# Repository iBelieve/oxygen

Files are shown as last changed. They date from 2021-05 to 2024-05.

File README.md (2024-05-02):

# Oxygen F7 Flight Controller

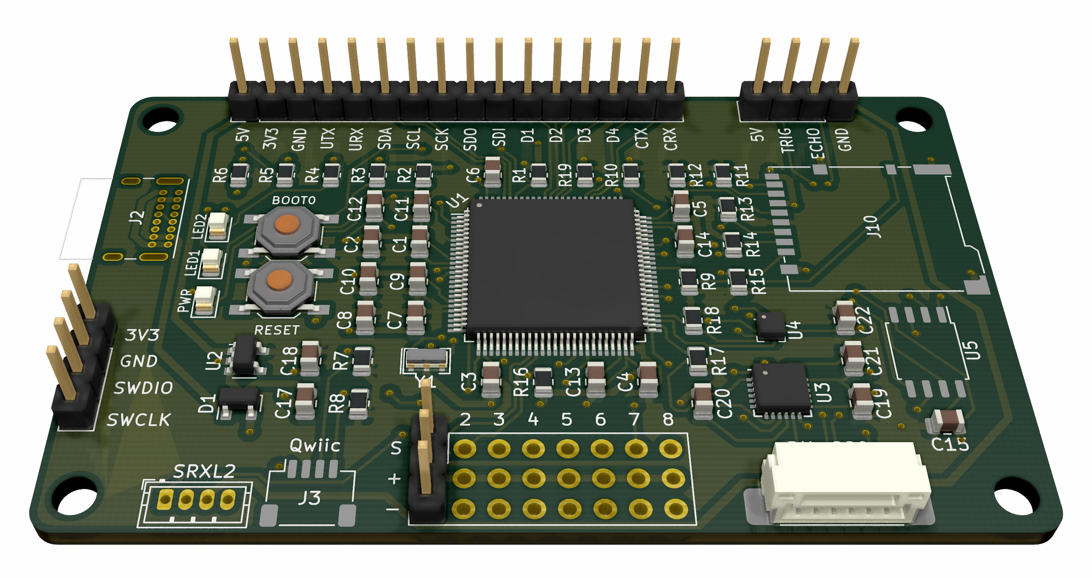
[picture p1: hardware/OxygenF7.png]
3D render of PCB


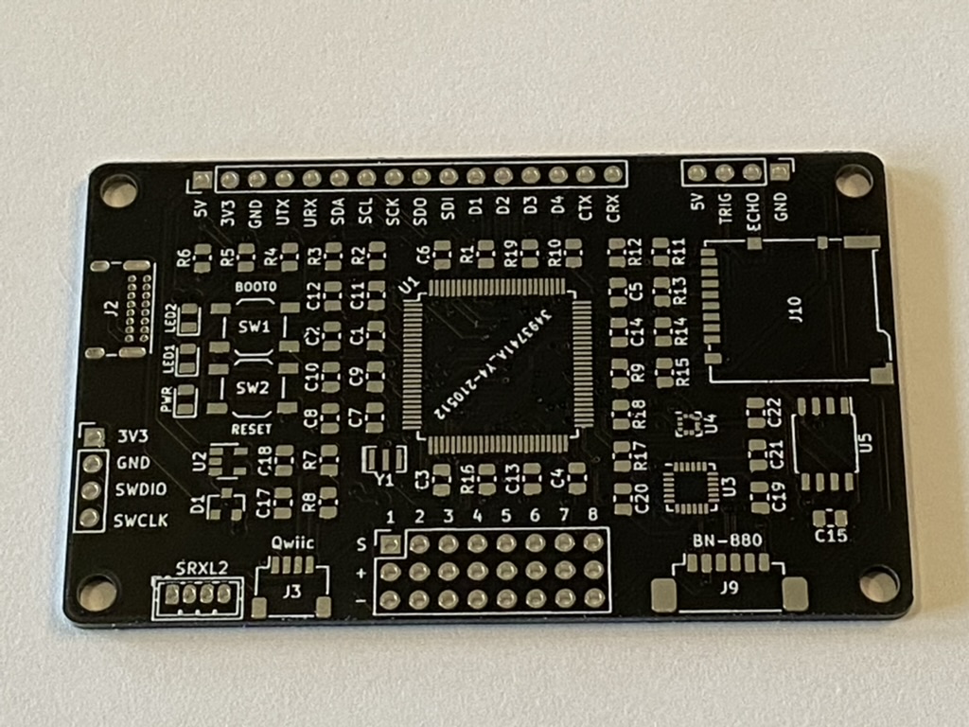
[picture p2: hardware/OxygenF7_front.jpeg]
Front of PCB

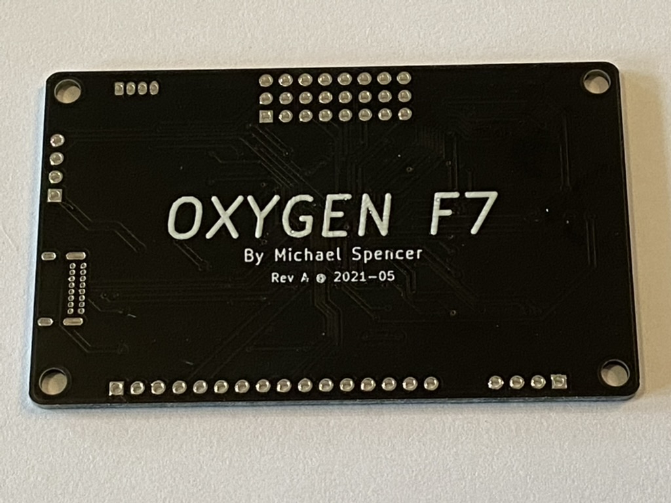
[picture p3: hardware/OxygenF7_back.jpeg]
Back of PCB

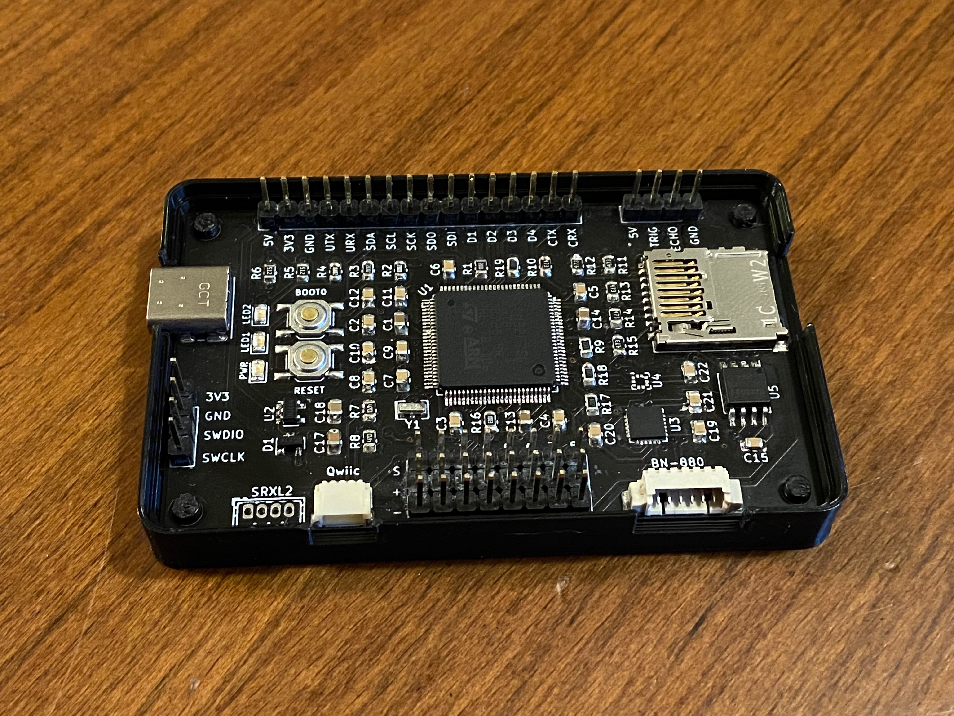
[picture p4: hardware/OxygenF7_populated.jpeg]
Populated PCB


## Hardware

- Designed for fixed-wing aircraft
- STM32F756
- MPU-6000 gyroscope & accelerometer
- BMP-388 barometer
- 8 PWM servo outputs
- SRXL2 receiver input
- Qwiic I2C port
- Connector for HC SR-04 ultrasonic distance sensor
- Connector for BN-880Q GPS and compass
- Header with various pins for debugging and experimentation
- USB-C
- microSD slot
- 128MB external flash memory

## Firmware

- Built with Rust
- Very early work-in-progress!!

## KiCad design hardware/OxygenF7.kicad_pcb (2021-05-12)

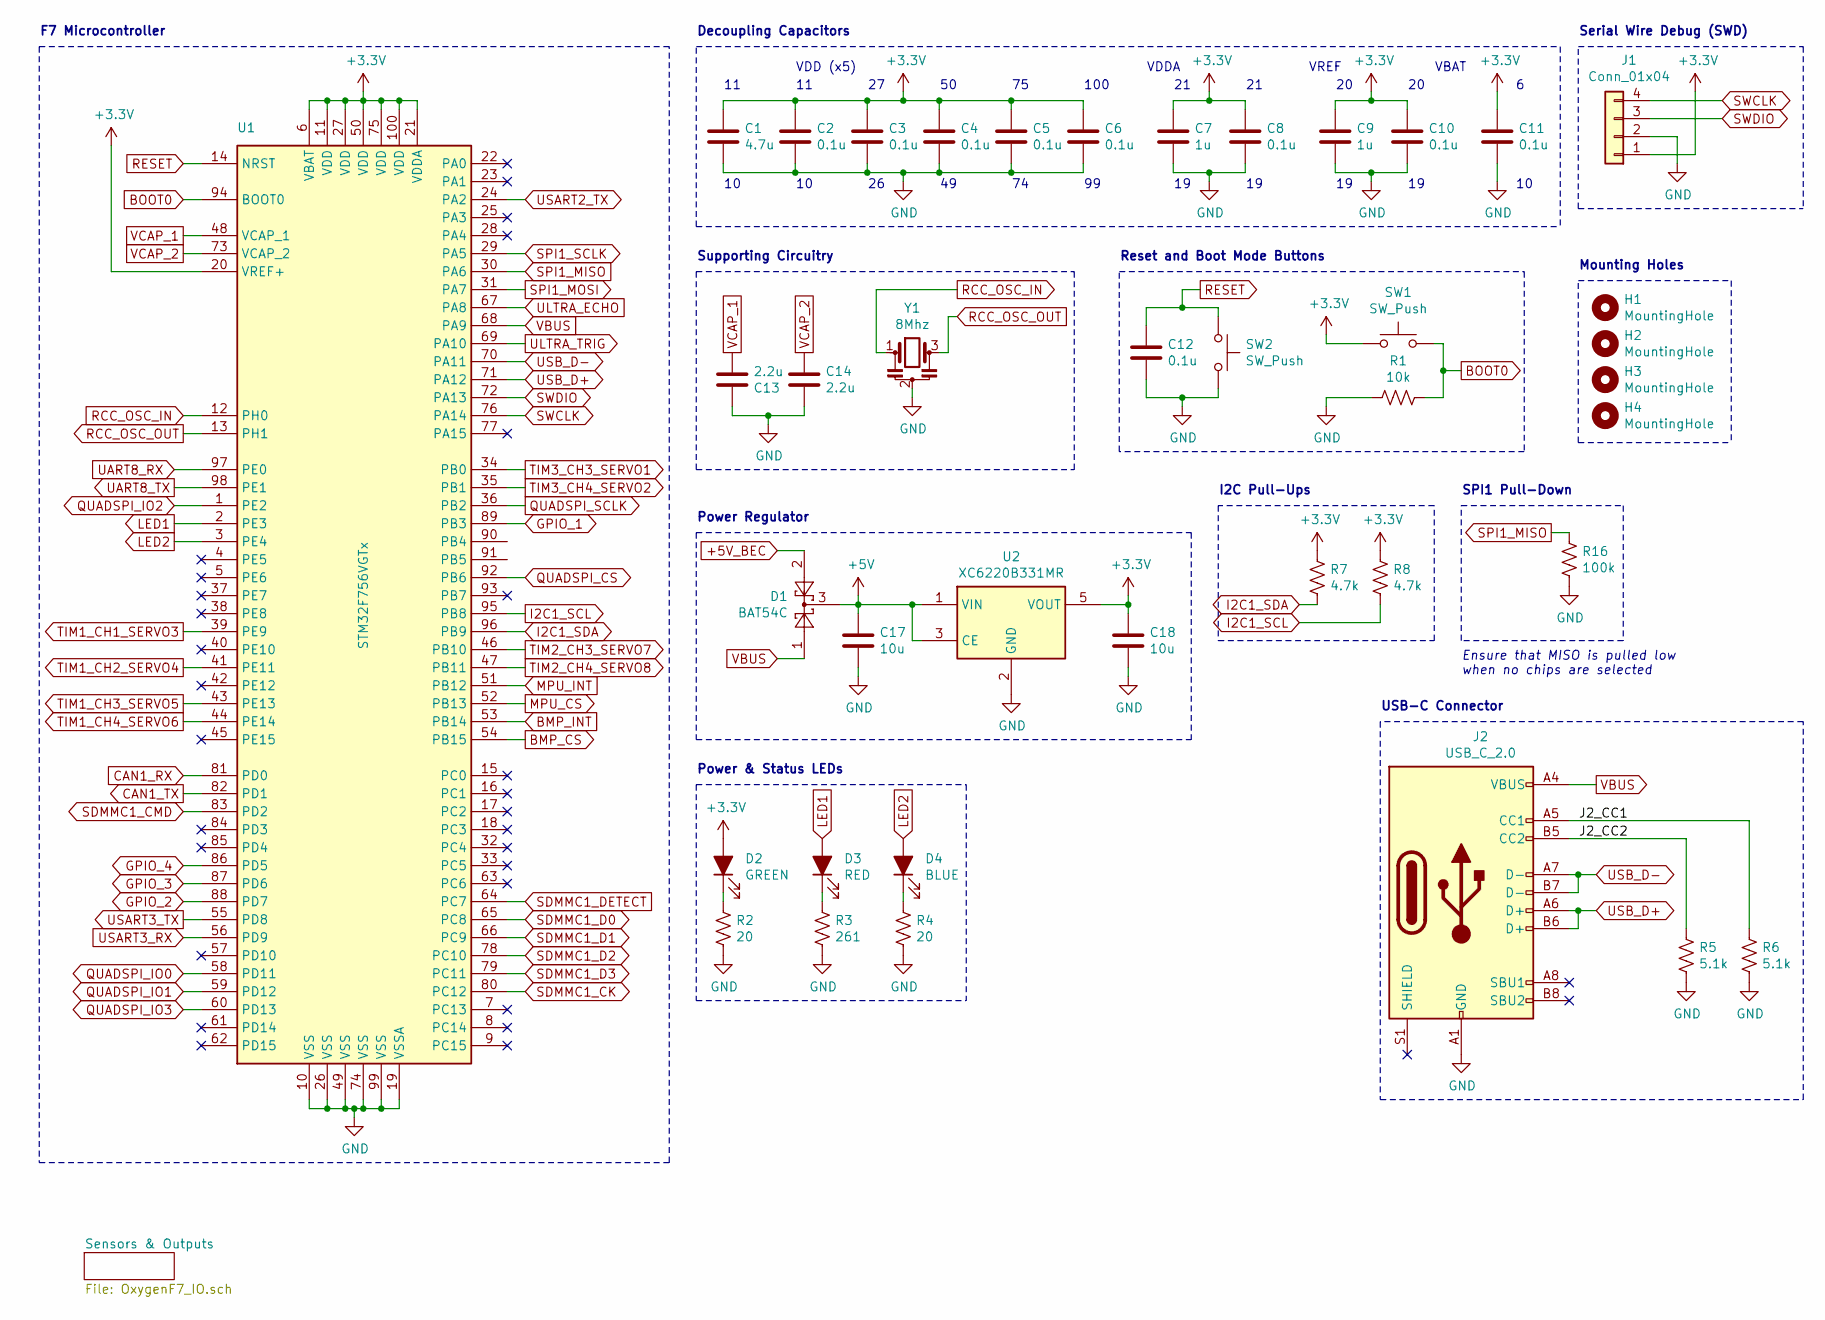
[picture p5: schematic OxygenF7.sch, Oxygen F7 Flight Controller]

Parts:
C1: 4.7u; C_0805_2012Metric; Part# CL21B475KPFNNNE
C2, C3, C4, C5, C6, C8, C10, C11, C12: 0.1u; C_0805_2012Metric; Part# CL21B104KBCNNNC‎
C7, C9: 1u; C_0805_2012Metric; Part# CL21B105KOFNNNG
C13, C14: 2.2u; C_0805_2012Metric; Part# CL21B225KPFNNNE
C17, C18: 10u; C_0805_2012Metric; Part# CL21B106KQQNNNG
D1: BAT54C; SOT-23; Part# BAT54CQ-7-F
D2: GREEN; LED_0805_2012Metric; Part# 150080GS75000
D3: RED; LED_0805_2012Metric; Part# 150080RS75000
D4: BLUE; LED_0805_2012Metric; Part# 150080BS75000
H1, H2, H3, H4: MountingHole; MountingHole_3.2mm_M3
J1: Conn_01x04; PinHeader_1x04_P2.54mm_Vertical; Part# PR20204VBNN
J2: USB_C_2.0; USB_C_Receptacle_GCT_USB4085; Part# USB4085-GF-A
R1: 10k; R_0805_2012Metric; Part# RMCF0805FT10K0
R2, R4: 20; R_0805_2012Metric; Part# RMCF0805FT20R0
R3: 261; R_0805_2012Metric; Part# RMCF0805FT261R
R5, R6: 5.1k; R_0805_2012Metric; Part# RMCF0805JT5K10
R7, R8: 4.7k; R_0805_2012Metric; Part# RMCF0805FT4K70
R16: 100k; R_0805_2012Metric; Part# RMCF0805FT100K
SW1, SW2: SW_Push; SW_SPST_TL3342; Part# TL3342F160QG/TR
U1: STM32F756VGTx; LQFP-100_14x14mm_P0.5mm; Part# STM32F756VGT6
U2: XC6220B331MR; SOT-23-5; Part# XC6220B331MR-G
Y1: 8Mhz; Resonator_SMD_muRata_CSTxExxV-3Pin_3.0x1.1mm; Part# CSTNE8M00GH5L000R0

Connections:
+3V3: C1.1, C2.1, C3.1, C4.1, C5.1, C6.1, C7.1, C8.1, C9.1, C10.1, C11.1, C18.1, D2.2 (A), J1.1, R7.1, R8.1, SW1.1, U1.6 (VBAT), U1.11 (VDD), U1.20 (VREF+), U1.21 (VDDA), U1.27 (VDD), U1.50 (VDD), U1.75 (VDD), U1.100 (VDD), U2.5 (VOUT); also elsewhere on the board
+5V: C17.1, D1.3, U2.1 (VIN), U2.3 (CE); also elsewhere on the board
+5V_BEC: D1.2; also elsewhere on the board
/J2_CC1: J2.A5 (CC1), R6.1
/J2_CC2: J2.B5 (CC2), R5.1
BMP_CS: U1.54 (PB15); also elsewhere on the board
BMP_INT: U1.53 (PB14); also elsewhere on the board
BOOT0: R1.2, SW1.2, U1.94 (BOOT0)
CAN1_RX: U1.81 (PD0); also elsewhere on the board
CAN1_TX: U1.82 (PD1); also elsewhere on the board
GND: C1.2, C2.2, C3.2, C4.2, C5.2, C6.2, C7.2, C8.2, C9.2, C10.2, C11.2, C12.2, C13.1, C14.2, C17.2, C18.2, J1.2, J2.A1 (GND), J2.A12 (GND), J2.B1 (GND), J2.B12 (GND), R1.1, R2.2, R3.2, R4.2, R5.2, R6.2, R16.2, SW2.2, U1.10 (VSS), U1.19 (VSSA), U1.26 (VSS), U1.49 (VSS), U1.74 (VSS), U1.99 (VSS), U2.2 (GND), Y1.2; also elsewhere on the board
GPIO_1: U1.89 (PB3); also elsewhere on the board
GPIO_2: U1.88 (PD7); also elsewhere on the board
GPIO_3: U1.87 (PD6); also elsewhere on the board
GPIO_4: U1.86 (PD5); also elsewhere on the board
I2C1_SCL: R8.2, U1.95 (PB8); also elsewhere on the board
I2C1_SDA: R7.2, U1.96 (PB9); also elsewhere on the board
LED1: D3.2 (A), U1.2 (PE3)
LED2: D4.2 (A), U1.3 (PE4)
MPU_CS: U1.52 (PB13); also elsewhere on the board
MPU_INT: U1.51 (PB12); also elsewhere on the board
unnamed: D2.1 (K), R2.1
unnamed: D3.1 (K), R3.1
unnamed: D4.1 (K), R4.1
QUADSPI_CS: U1.92 (PB6); also elsewhere on the board
QUADSPI_IO0: U1.58 (PD11); also elsewhere on the board
QUADSPI_IO1: U1.59 (PD12); also elsewhere on the board
QUADSPI_IO2: U1.1 (PE2); also elsewhere on the board
QUADSPI_IO3: U1.60 (PD13); also elsewhere on the board
QUADSPI_SCLK: U1.36 (PB2); also elsewhere on the board
RCC_OSC_IN: U1.12 (PH0), Y1.1
RCC_OSC_OUT: U1.13 (PH1), Y1.3
RESET: C12.1, SW2.1, U1.14 (NRST)
SDMMC1_CK: U1.80 (PC12); also elsewhere on the board
SDMMC1_CMD: U1.83 (PD2); also elsewhere on the board
SDMMC1_D0: U1.65 (PC8); also elsewhere on the board
SDMMC1_D1: U1.66 (PC9); also elsewhere on the board
SDMMC1_D2: U1.78 (PC10); also elsewhere on the board
SDMMC1_D3: U1.79 (PC11); also elsewhere on the board
SDMMC1_DETECT: U1.64 (PC7); also elsewhere on the board
SPI1_MISO: R16.1, U1.30 (PA6); also elsewhere on the board
SPI1_MOSI: U1.31 (PA7); also elsewhere on the board
SPI1_SCLK: U1.29 (PA5); also elsewhere on the board
SWCLK: J1.4, U1.76 (PA14)
SWDIO: J1.3, U1.72 (PA13)
TIM1_CH1_SERVO3: U1.39 (PE9); also elsewhere on the board
TIM1_CH2_SERVO4: U1.41 (PE11); also elsewhere on the board
TIM1_CH3_SERVO5: U1.43 (PE13); also elsewhere on the board
TIM1_CH4_SERVO6: U1.44 (PE14); also elsewhere on the board
TIM2_CH3_SERVO7: U1.46 (PB10); also elsewhere on the board
TIM2_CH4_SERVO8: U1.47 (PB11); also elsewhere on the board
TIM3_CH3_SERVO1: U1.34 (PB0); also elsewhere on the board
TIM3_CH4_SERVO2: U1.35 (PB1); also elsewhere on the board
UART8_RX: U1.97 (PE0); also elsewhere on the board
UART8_TX: U1.98 (PE1); also elsewhere on the board
ULTRA_ECHO: U1.67 (PA8); also elsewhere on the board
ULTRA_TRIG: U1.69 (PA10); also elsewhere on the board
USART2_TX: U1.24 (PA2); also elsewhere on the board
USART3_RX: U1.56 (PD9); also elsewhere on the board
USART3_TX: U1.55 (PD8); also elsewhere on the board
USB_D+: J2.A6 (D+), J2.B6 (D+), U1.71 (PA12)
USB_D-: J2.A7 (D-), J2.B7 (D-), U1.70 (PA11)
VBUS: D1.1, J2.A4 (VBUS), J2.A9 (VBUS), J2.B4 (VBUS), J2.B9 (VBUS), U1.68 (PA9)
VCAP_1: C13.2, U1.48 (VCAP_1)
VCAP_2: C14.1, U1.73 (VCAP_2)

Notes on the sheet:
Decoupling Capacitors
VDD (x5)
VDDA
F7 Microcontroller
VBAT
100
USB-C Connector
Power & Status LEDs
Supporting Circuitry
Power Regulator
Serial Wire Debug (SWD)
VREF
Mounting Holes
Reset and Boot Mode Buttons
I2C Pull-Ups
SPI1 Pull-Down
Ensure that MISO is pulled low when no chips are selected

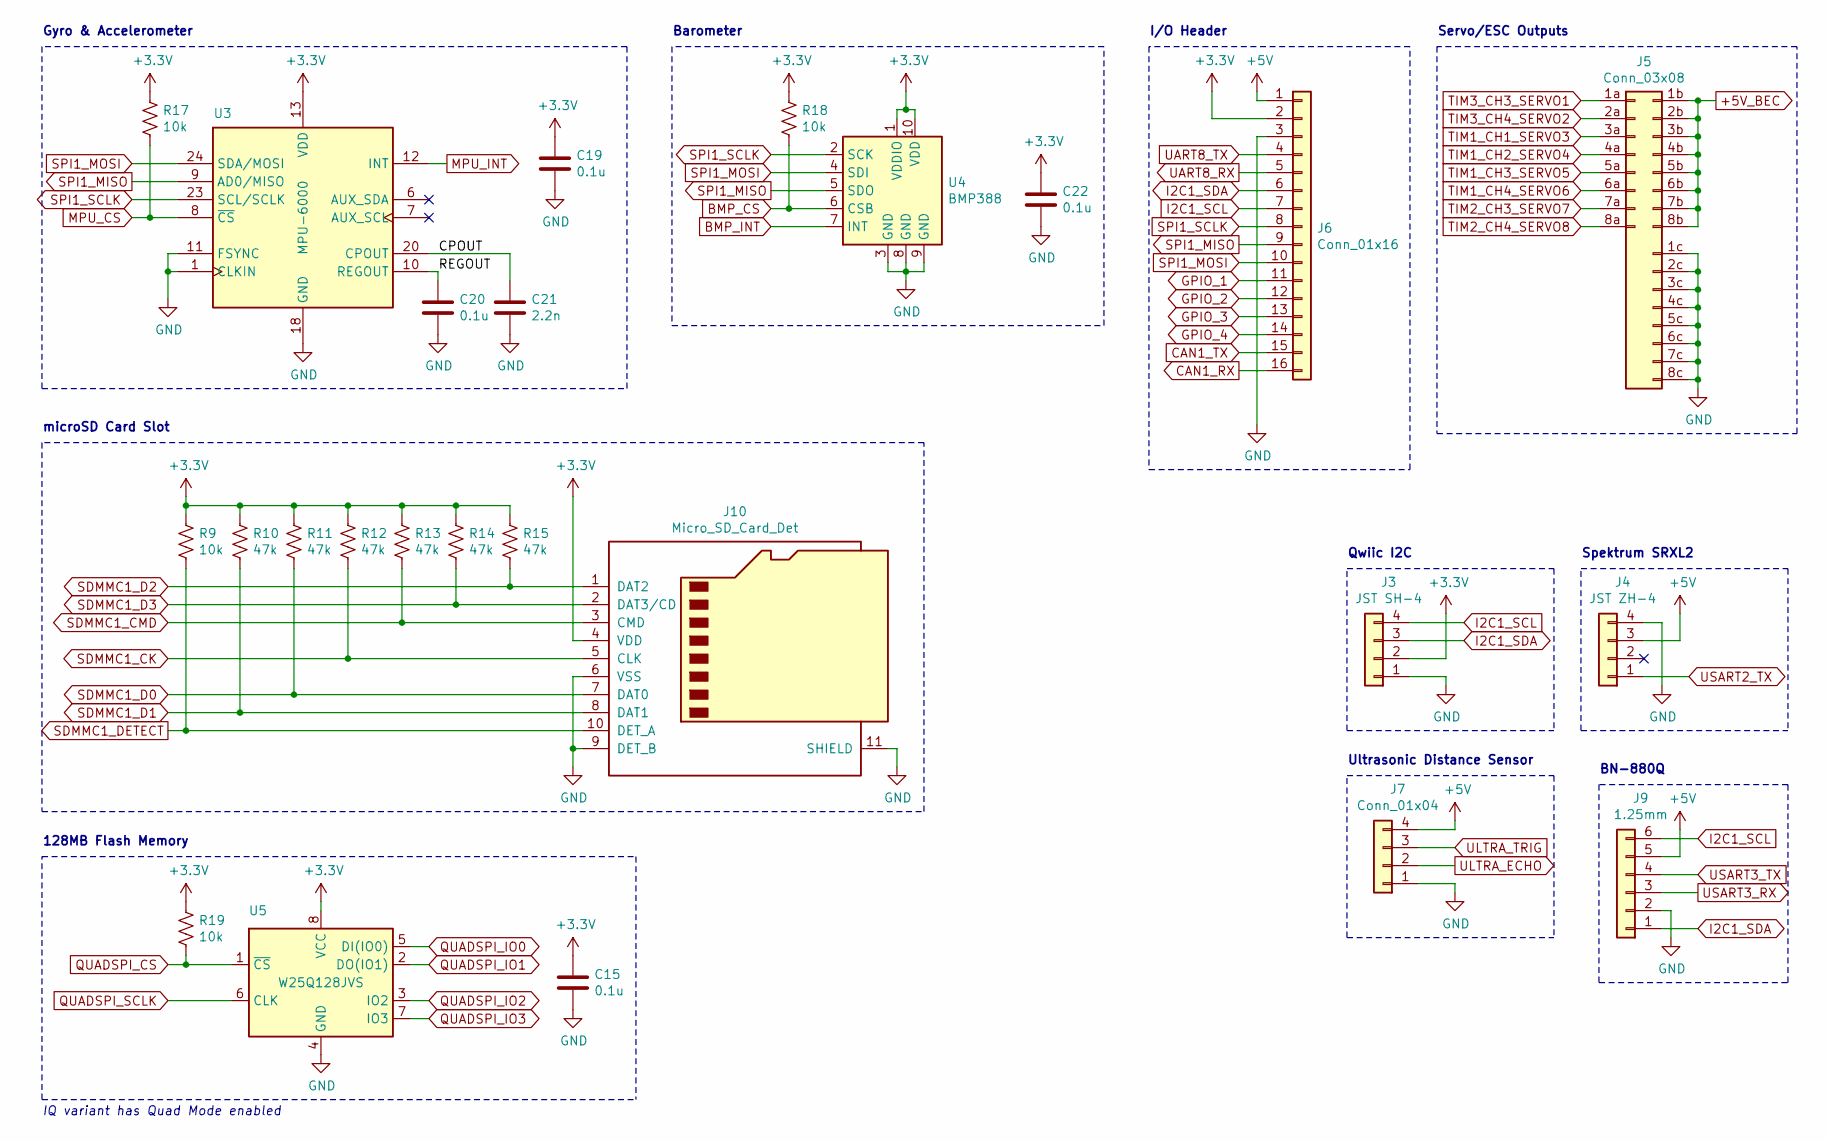
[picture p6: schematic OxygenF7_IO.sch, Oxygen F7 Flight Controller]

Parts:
C15, C19, C20, C22: 0.1u; C_0805_2012Metric; Part# CL21B104KBCNNNC‎
C21: 2.2n; C_0805_2012Metric; Part# CL21B222KBANNNC
J3: JST SH-4; JST_SH_SM04B-SRSS-TB_1x04-1MP_P1.00mm_Horizontal; Part# SM04B-SRSS-TB(LF)(SN)
J4: JST ZH-4; JST_ZH_B4B-ZR_1x04_P1.50mm_Vertical; Part# B4B-ZR-SM4-TF(LF)(SN)
J5: Conn_03x08; PinHeader_08x03_P2.54mm_Vertical; Part# PR20208VBNN:3
J6: Conn_01x16; PinHeader_1x16_P2.54mm_Vertical; Part# 61301611121
J7: Conn_01x04; PinHeader_1x04_P2.54mm_Vertical; Part# PR20204VBNN
J9: 1.25mm; 10114830-10106LF_P1.25mm_Horizontal; Part# 10114830-10106LF
J10: Micro_SD_Card_Det; microSD_HC_Hirose_DM3BT-DSF-PEJS; Part# DM3BT-DSF-PEJS
R9, R17, R18, R19: 10k; R_0805_2012Metric; Part# RMCF0805FT10K0
R10, R11, R12, R13, R14, R15: 47k; R_0805_2012Metric; Part# RMCF0805JT47K0
U3: MPU-6000; InvenSense_QFN-24_4x4mm_P0.5mm; Part# MPU-6000
U4: BMP388; LGA-10_2x2mm_P0.5mm; Part# BMP388
U5: W25Q128JVS; SOIC-8_5.23x5.23mm_P1.27mm; Part# W25Q128JVSIQ

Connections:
+3V3: C15.1, C19.1, C22.1, J3.2, J6.2, J10.4 (VDD), R9.1, R10.1, R11.1, R12.1, R13.1, R14.1, R15.1, R17.1, R18.1, R19.1, U3.13 (VDD), U4.1 (VDDIO), U4.10 (VDD), U5.8 (VCC); also elsewhere on the board
+5V: J4.3, J6.1, J7.4, J9.5; also elsewhere on the board
+5V_BEC: J5.1b, J5.2b, J5.3b, J5.4b, J5.5b, J5.6b, J5.7b, J5.8b; also elsewhere on the board
/Sensors & Outputs/CPOUT: C21.1, U3.20 (CPOUT)
/Sensors & Outputs/REGOUT: C20.1, U3.10 (REGOUT)
BMP_CS: R18.2, U4.6 (CSB); also elsewhere on the board
BMP_INT: U4.7 (INT); also elsewhere on the board
CAN1_RX: J6.16; also elsewhere on the board
CAN1_TX: J6.15; also elsewhere on the board
GND: C15.2, C19.2, C20.2, C21.2, C22.2, J3.1, J4.4, J5.1c, J5.2c, J5.3c, J5.4c, J5.5c, J5.6c, J5.7c, J5.8c, J6.3, J7.1, J9.2, J10.6 (VSS), J10.9 (DET_B), J10.11 (SHIELD), U3.1 (CLKIN), U3.11 (FSYNC), U3.18 (GND), U4.3 (GND), U4.8 (GND), U4.9 (GND), U5.4 (GND); also elsewhere on the board
GPIO_1: J6.11; also elsewhere on the board
GPIO_2: J6.12; also elsewhere on the board
GPIO_3: J6.13; also elsewhere on the board
GPIO_4: J6.14; also elsewhere on the board
I2C1_SCL: J3.4, J6.7, J9.6; also elsewhere on the board
I2C1_SDA: J3.3, J6.6, J9.1; also elsewhere on the board
MPU_CS: R17.2, U3.8 (~CS); also elsewhere on the board
MPU_INT: U3.12 (INT); also elsewhere on the board
QUADSPI_CS: R19.2, U5.1 (~CS); also elsewhere on the board
QUADSPI_IO0: U5.5 (DI(IO0)); also elsewhere on the board
QUADSPI_IO1: U5.2 (DO(IO1)); also elsewhere on the board
QUADSPI_IO2: U5.3 (IO2); also elsewhere on the board
QUADSPI_IO3: U5.7 (IO3); also elsewhere on the board
QUADSPI_SCLK: U5.6 (CLK); also elsewhere on the board
SDMMC1_CK: J10.5 (CLK), R12.2; also elsewhere on the board
SDMMC1_CMD: J10.3 (CMD), R13.2; also elsewhere on the board
SDMMC1_D0: J10.7 (DAT0), R11.2; also elsewhere on the board
SDMMC1_D1: J10.8 (DAT1), R10.2; also elsewhere on the board
SDMMC1_D2: J10.1 (DAT2), R15.2; also elsewhere on the board
SDMMC1_D3: J10.2 (DAT3/CD), R14.2; also elsewhere on the board
SDMMC1_DETECT: J10.10 (DET_A), R9.2; also elsewhere on the board
SPI1_MISO: J6.9, U3.9 (AD0/MISO), U4.5 (SDO); also elsewhere on the board
SPI1_MOSI: J6.10, U3.24 (SDA/MOSI), U4.4 (SDI); also elsewhere on the board
SPI1_SCLK: J6.8, U3.23 (SCL/SCLK), U4.2 (SCK); also elsewhere on the board
TIM1_CH1_SERVO3: J5.3a; also elsewhere on the board
TIM1_CH2_SERVO4: J5.4a; also elsewhere on the board
TIM1_CH3_SERVO5: J5.5a; also elsewhere on the board
TIM1_CH4_SERVO6: J5.6a; also elsewhere on the board
TIM2_CH3_SERVO7: J5.7a; also elsewhere on the board
TIM2_CH4_SERVO8: J5.8a; also elsewhere on the board
TIM3_CH3_SERVO1: J5.1a; also elsewhere on the board
TIM3_CH4_SERVO2: J5.2a; also elsewhere on the board
UART8_RX: J6.5; also elsewhere on the board
UART8_TX: J6.4; also elsewhere on the board
ULTRA_ECHO: J7.2; also elsewhere on the board
ULTRA_TRIG: J7.3; also elsewhere on the board
USART2_TX: J4.1; also elsewhere on the board
USART3_RX: J9.3; also elsewhere on the board
USART3_TX: J9.4; also elsewhere on the board

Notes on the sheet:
Qwiic I2C
Spektrum SRXL2
Ultrasonic Distance Sensor
Barometer
Gyro & Accelerometer
I/O Header
microSD Card Slot
Servo/ESC Outputs
BN-880Q
128MB Flash Memory
IQ variant has Quad Mode enabled

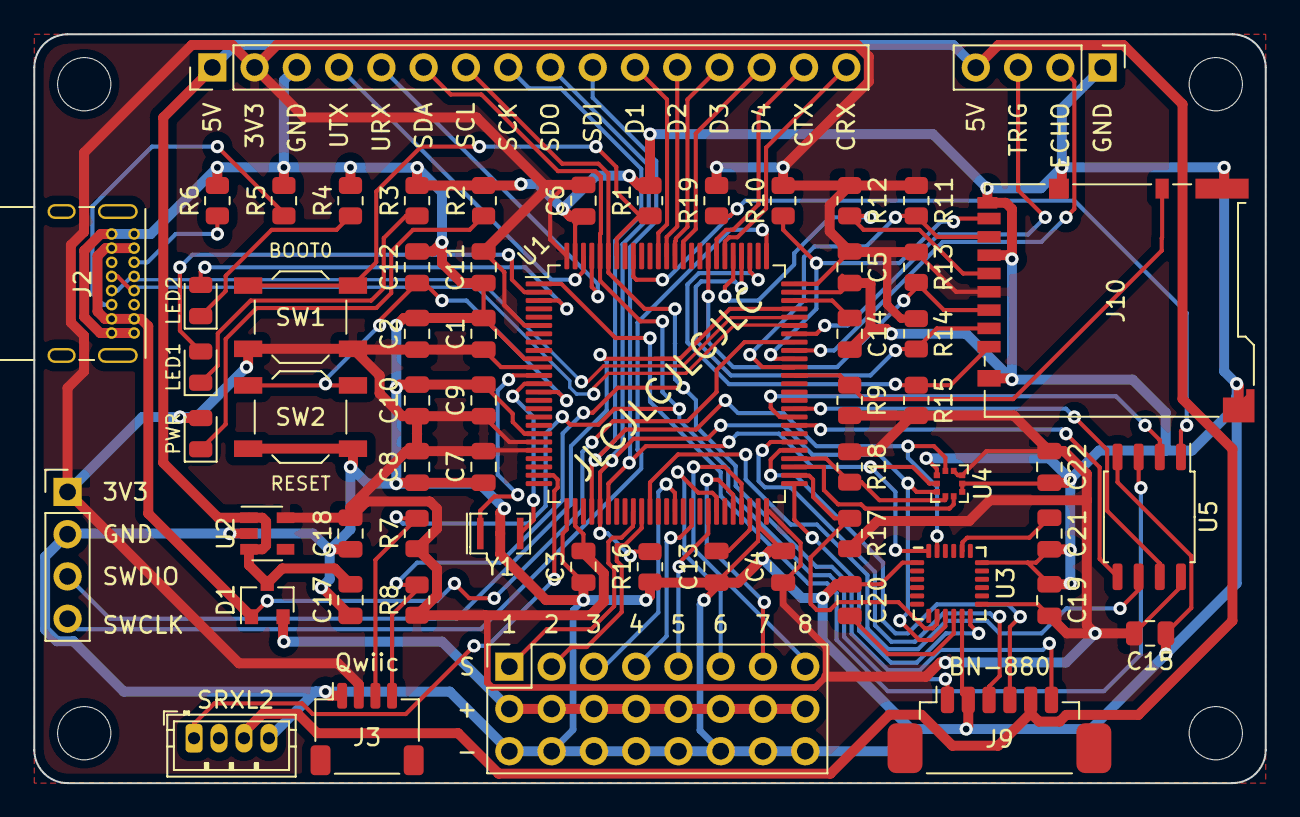
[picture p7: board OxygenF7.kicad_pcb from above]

Board: 2 copper layers, 74.0 x 45.0 mm, 65 parts (0 on the bottom side), 67 nets.

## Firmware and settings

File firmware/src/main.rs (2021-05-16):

// #![deny(unsafe_code)]
#![no_main]
#![no_std]

extern crate panic_rtt_target;

// mod boards;
// mod device;
// mod mpu6000;
mod clock;
mod drivers;

use embedded_hal::blocking::delay::DelayMs;
// use mpu6000::{
//     bus::{Bus, SpiBus},
//     registers::{AccelerometerSensitive, GyroSensitive},
//     MPU6000,
// };
use crate::clock::SysClock;
use crate::drivers::Servos;
use embedded_time::Clock;
use rtic::app;
use rtt_target::{rprintln, rtt_init_print};
use stm32f7xx_hal::gpio::gpioa::{PA10, PA8};
use stm32f7xx_hal::gpio::{Floating, Input, Output, PushPull};
use stm32f7xx_hal::pac::{EXTI, TIM1, TIM2, TIM3, TIM4};
use stm32f7xx_hal::pwm::{PwmChannels, C1, C2, C3, C4};
use stm32f7xx_hal::timer::Event;
use stm32f7xx_hal::{
    delay::Delay,
    gpio::{self, Edge, ExtiPin},
    i2c::{self, I2c},
    pac,
    prelude::*,
    pwm,
    rcc::{HSEClock, HSEClockMode},
    spi::{self, Spi},
    time::KiloHertz,
    timer::Timer,
};

type I2C1 = I2c<
    pac::I2C1,
    gpio::gpiob::PB8<gpio::Alternate<gpio::AF4>>,
    gpio::gpiob::PB9<gpio::Alternate<gpio::AF4>>,
>;

type SPI1 = Spi<
    pac::SPI1,
    (
        gpio::gpioa::PA5<gpio::Alternate<gpio::AF5>>,
        gpio::gpioa::PA6<gpio::Alternate<gpio::AF5>>,
        gpio::gpioa::PA7<gpio::Alternate<gpio::AF5>>,
    ),
    spi::Enabled<u8>,
>;

type TriggerPin = PA10<Output<PushPull>>;
type EchoPin = PA8<Input<Floating>>;
type HcSr04 = crate::drivers::HcSr04<TriggerPin>;

#[app(device = stm32f7xx_hal::pac, peripherals = true)]
const APP: () = {
    struct Resources {
        delay: Delay,
        servos: Servos,
        clock: SysClock,
        hcsr04_timer: Timer<TIM4>,
        hcsr04: HcSr04,
        echo_pin: EchoPin,
    }

    #[init]
    fn init(ctx: init::Context) -> init::LateResources {
        rtt_init_print!();
        rprintln!("Welcome to Oxygen F7");

        let core: cortex_m::Peripherals = ctx.core;
        let mut device: stm32f7xx_hal::pac::Peripherals = ctx.device;

        let gpioa = device.GPIOA.split();
        let gpiob = device.GPIOB.split();
        let gpioe = device.GPIOE.split();

        // LED pins
        let mut led1 = gpioe.pe2.into_push_pull_output();
        let mut led2 = gpioe.pe3.into_push_pull_output();

        // Set LED pins to high to indicate flight controller is working
        led1.set_high().unwrap();
        led2.set_high().unwrap();

        // MPU Interrupt pin
        let mut mpu_int = gpiob.pb12.into_floating_input();
        mpu_int.make_interrupt_source(&mut device.SYSCFG, &mut device.RCC);
        mpu_int.trigger_on_edge(&mut device.EXTI, Edge::Rising);
        mpu_int.enable_interrupt(&mut device.EXTI);

        // BMP Interrupt pin
        let mut bmp_int = gpiob.pb14.into_floating_input();
        bmp_int.make_interrupt_source(&mut device.SYSCFG, &mut device.RCC);
        bmp_int.trigger_on_edge(&mut device.EXTI, Edge::Rising);
        bmp_int.enable_interrupt(&mut device.EXTI);

        // MPU and BMP chip select pins
        let mut mpu_cs = gpiob.pb13.into_push_pull_output();
        let mut bmp_cs = gpiob.pb15.into_push_pull_output();

        // Set CS pins to high (disabled) initially
        mpu_cs.set_high().unwrap();
        bmp_cs.set_high().unwrap();

        // Distance Sensor
        let hcsr04 = HcSr04::new(gpioa.pa10.into_push_pull_output())
            .expect("Unable to initialize HC SR-04 ultrasonic distance sensor");

        let mut echo_pin = gpioa.pa8.into_floating_input();
        echo_pin.make_interrupt_source(&mut device.SYSCFG, &mut device.RCC);
        echo_pin.trigger_on_edge(&mut device.EXTI, Edge::RisingFalling);
        echo_pin.enable_interrupt(&mut device.EXTI);

        // Constrain clocking registers
        let mut rcc = device.RCC.constrain();

        // Configure clock and freeze it
        let clocks = rcc
            .cfgr
            .hse(HSEClock::new(8.mhz(), HSEClockMode::Oscillator))
            .sysclk(216.mhz())
            .freeze();

        // Distance sensor trigger timer
        let mut hcsr04_timer = Timer::tim4(device.TIM4, 10.hz(), clocks, &mut rcc.apb1);
        hcsr04_timer.listen(Event::TimeOut);

        // Monotonic clock
        let clock = SysClock::new(device.TIM5, clocks);

        // Get delay provider
        let mut delay = Delay::new(core.SYST, clocks);

        // Servos!
        let servos = Servos::new(
            clocks,
            device.TIM1,
            device.TIM2,
            device.TIM3,
            gpiob.pb0.into_alternate_af2(),
            gpiob.pb1.into_alternate_af2(),
            gpioe.pe9.into_alternate_af1(),
            gpioe.pe11.into_alternate_af1(),
            gpioe.pe13.into_alternate_af1(),
            gpioe.pe14.into_alternate_af1(),
            gpiob.pb10.into_alternate_af1(),
            gpiob.pb11.into_alternate_af1(),
        );

        // I2C1
        let scl = gpiob.pb8.into_alternate_af4();
        let sda = gpiob.pb9.into_alternate_af4();

        let i2c1 = I2c::i2c1(
            device.I2C1,
            (scl, sda),
            i2c::Mode::standard(400.khz()),
            clocks,
            &mut rcc.apb1,
        );

        let i2c1_shared: &'static _ = shared_bus::new_atomic_check!(I2C1 = i2c1).unwrap();

        // SPI1
        let sck = gpioa.pa5.into_alternate_af5();
        let miso = gpioa.pa6.into_alternate_af5();
        let mosi = gpioa.pa7.into_alternate_af5();

        let spi1 = Spi::new(device.SPI1, (sck, miso, mosi)).enable::<u8>(
            &mut rcc.apb2,             // 108 MHz
            spi::ClockDivider::DIV128, // 108/128 = 0.84Mhz (must be 1MHz or less)
            spi::Mode {
                polarity: spi::Polarity::IdleHigh,
                phase: spi::Phase::CaptureOnSecondTransition,
            },
        );

        let spi1_shared: &'static _ = shared_bus::new_atomic_check!(SPI1 = spi1).unwrap();

        // let spi_bus = SpiBus::new(spi, mpu_ncs, delay);
        // let mut mpu6000 = MPU6000::new(spi_bus);
        // mpu6000.reset(&mut delay).unwrap();
        // mpu6000.wake(&delay).unwrap();
        // mpu6000
        //     .set_accelerometer_sensitive(accelerometer_sensitive!(+/-16g, 2048/LSB))
        //     .unwrap();
        // mpu6000
        //     .set_gyro_sensitive(gyro_sensitive!(+/-2000dps, 16.4LSB/dps))
        //     .unwrap();

        init::LateResources {
            delay,
            clock,
            hcsr04_timer,
            hcsr04,
            echo_pin,
            servos,
        }
    }

    #[task(binds = TIM4, resources = [delay, hcsr04_timer, hcsr04])]
    fn hcsr04_timer(ctx: hcsr04_timer::Context) {
        let delay: &mut Delay = ctx.resources.delay;
        let timer: &mut Timer<TIM4> = ctx.resources.hcsr04_timer;
        let hcsr04: &mut HcSr04 = ctx.resources.hcsr04;

        timer.clear_interrupt(Event::TimeOut);

        hcsr04
            .trigger(delay)
            .expect("Unable to trigger distance reading");
    }

    #[task(binds = EXTI9_5, resources = [clock, echo_pin, hcsr04])]
    fn exti9_5(ctx: exti9_5::Context) {
        let echo_pin: &mut EchoPin = ctx.resources.echo_pin;
        let clock: &mut SysClock = ctx.resources.clock;
        let hcsr04: &mut HcSr04 = ctx.resources.hcsr04;

        let now = clock
            .try_now()
            .expect("Unable to get current time from system clock");

        if echo_pin.check_interrupt() {
            echo_pin.clear_interrupt_pending_bit();

            if echo_pin.is_high().unwrap() {
                hcsr04
                    .on_echo_start(now)
                    .expect("Error handling HC-SR04 echo start");
            } else {
                let dist_mm = hcsr04
                    .on_echo_end(now)
                    .expect("Error handling HC-SR04 echo end");
                rprintln!("Current distance: {}mm", dist_mm);
            }
        } else {
            rprintln!("Unexpected EXTI9_5 interrupt");
        }
    }
};

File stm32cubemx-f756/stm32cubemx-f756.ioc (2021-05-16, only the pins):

Mcu.UserName=STM32F756VGTx
PA11.Signal=USB_OTG_FS_DM
PA12.Signal=USB_OTG_FS_DP
PA13.Signal=SYS_JTMS-SWDIO
PA14.Signal=SYS_JTCK-SWCLK
PA5.Signal=SPI1_SCK
PA6.Signal=SPI1_MISO
PA7.Signal=SPI1_MOSI
PA9.Signal=USB_OTG_FS_VBUS
PB10.Signal=SPI2_SCK
PB2.Signal=QUADSPI_CLK
PB6.Signal=QUADSPI_BK1_NCS
PB8.Signal=I2C1_SCL
PB9.Signal=I2C1_SDA
PC1.Signal=SPI2_MOSI
PC10.Signal=SDMMC1_D2
PC11.Signal=SDMMC1_D3
PC12.Signal=SDMMC1_CK
PC2.Signal=SPI2_MISO
PC8.Signal=SDMMC1_D0
PC9.Signal=SDMMC1_D1
PD0.Signal=CAN1_RX
PD1.Signal=CAN1_TX
PD11.Signal=QUADSPI_BK1_IO0
PD12.Signal=QUADSPI_BK1_IO1
PD13.Signal=QUADSPI_BK1_IO3
PD2.Signal=SDMMC1_CMD
PE0.Signal=UART8_RX
PE1.Signal=UART8_TX
PE12.Signal=SPI4_SCK
PE2.Signal=QUADSPI_BK1_IO2
PE5.Signal=SPI4_MISO
PE6.Signal=SPI4_MOSI
PH0/OSC_IN.Signal=RCC_OSC_IN
PH1/OSC_OUT.Signal=RCC_OSC_OUT

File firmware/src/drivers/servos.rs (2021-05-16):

use embedded_hal::PwmPin;
use stm32f7xx_hal::gpio::gpiob::{PB0, PB1, PB10, PB11};
use stm32f7xx_hal::gpio::gpioe::{PE11, PE13, PE14, PE9};
use stm32f7xx_hal::gpio::{Alternate, AF1, AF2};
use stm32f7xx_hal::pac::{TIM1, TIM2, TIM3};
use stm32f7xx_hal::pwm::{self, PwmChannels, C1, C2, C3, C4};
use stm32f7xx_hal::rcc::Clocks;
use stm32f7xx_hal::time::KiloHertz;

const SERVO_PWM_FREQUENCY: KiloHertz = KiloHertz(50);

pub struct Servos {
    ch1: PwmChannels<TIM3, C3>,
    ch2: PwmChannels<TIM3, C4>,
    ch3: PwmChannels<TIM1, C1>,
    ch4: PwmChannels<TIM1, C2>,
    ch5: PwmChannels<TIM1, C3>,
    ch6: PwmChannels<TIM1, C4>,
    ch7: PwmChannels<TIM2, C3>,
    ch8: PwmChannels<TIM2, C4>,
}

impl Servos {
    pub fn new(
        clocks: Clocks,
        tim1: TIM1,
        tim2: TIM2,
        tim3: TIM3,
        pb0: PB0<Alternate<AF2>>,
        pb1: PB1<Alternate<AF2>>,
        pe9: PE9<Alternate<AF1>>,
        pe11: PE11<Alternate<AF1>>,
        pe13: PE13<Alternate<AF1>>,
        pe14: PE14<Alternate<AF1>>,
        pb10: PB10<Alternate<AF1>>,
        pb11: PB11<Alternate<AF1>>,
    ) -> Self {
        let (mut ch1, mut ch2) = pwm::tim3(tim3, (pb0, pb1), clocks, SERVO_PWM_FREQUENCY);
        let (mut ch3, mut ch4, mut ch5, mut ch6) =
            pwm::tim1(tim1, (pe9, pe11, pe13, pe14), clocks, SERVO_PWM_FREQUENCY);
        let (mut ch7, mut ch8) = pwm::tim2(tim2, (pb10, pb11), clocks, SERVO_PWM_FREQUENCY);

        ch1.set_duty(ch1.get_max_duty() * 1000 / 20_000); // Motor off
        ch2.set_duty(ch2.get_max_duty() * 1500 / 20_000); // Servo centered
        ch3.set_duty(ch3.get_max_duty() * 1500 / 20_000); // Servo centered
        ch4.set_duty(ch4.get_max_duty() * 1500 / 20_000); // Servo centered

        // ch5.set_duty(ch5.get_max_duty() * 1500 / 20_000); // Servo centered
        // ch6.set_duty(ch6.get_max_duty() * 1500 / 20_000); // Servo centered
        // ch7.set_duty(ch7.get_max_duty() * 1500 / 20_000); // Servo centered
        // ch8.set_duty(ch8.get_max_duty() * 1500 / 20_000); // Servo centered

        ch1.enable();
        ch2.enable();
        ch3.enable();
        ch4.enable();
        // ch5.enable();
        // ch6.enable();
        // ch7.enable();
        // ch8.enable();

        Servos {
            ch1,
            ch2,
            ch3,
            ch4,
            ch5,
            ch6,
            ch7,
            ch8,
        }
    }
}

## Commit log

2021-04-24 Initial project
    [OxygenF7.kicad_pcb, OxygenF7.sch, OxygenF7_IO.sch]
2021-05-08 Swap out some out-of-stock parts
    [OxygenF7.kicad_pcb, OxygenF7.sch, OxygenF7_IO.sch]
2021-05-09 Don't ground unused MCU pins and add microSD pull-up resistors
    [OxygenF7.sch, OxygenF7_IO.sch]
2021-05-09 Add more pull-up/pull-down resistors and 128MB flash memory
    [OxygenF7.sch, OxygenF7_IO.sch]
2021-05-11 New board layout
    [OxygenF7.kicad_pcb, OxygenF7.sch, OxygenF7_IO.sch]
2021-05-11 Update clearances to satisfy DRC
    [OxygenF7.kicad_pcb]
2021-05-11 Update resistor values for status LED to use only 5mA
    [OxygenF7.kicad_pcb, OxygenF7.sch]
2021-05-11 Small layout tweaks
    [OxygenF7.kicad_pcb, OxygenF7.sch]
2021-05-12 Small tweaks
    [OxygenF7.kicad_pcb, OxygenF7.sch]
2021-05-16 Refactor servo logic into separate module
2021-05-16 Add STM32CubeMX project
2021-05-16 Add screenshot of current board design
2021-05-16 Remove old F765-based hardware design
    [OxygenF7.kicad_pcb, OxygenF7.sch, OxygenF7_IO.sch]
2021-05-16 Rename hardware-f756 to just hardware
    [OxygenF7.kicad_pcb, OxygenF7.sch, OxygenF7_IO.sch]
2024-05-02 Add photos of the completed PCB
